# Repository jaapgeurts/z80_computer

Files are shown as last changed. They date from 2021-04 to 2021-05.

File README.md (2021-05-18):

# Sea80 1648 : Z80 Homebrew computer

This project contains the following subprojects

1. Hardware Schematic and PCB design
2. Retro8 compiler - compiler for z80
3. Firmware, rom monitor, gal files, general test utilities

System clock: 7,372,800 Hz

Notes to self:
My z80 and peripheral chips have been relabeled(sanded and repainted) by Chinese sellers. The SIO in my system is a SIO/0

# Hardware

##  Memory map

Memory is divided into 8K block

0000-1FFF = ROM chip U6
2000-3FFF = ROM chip U7
4000-5FFF = RAM chip U8
6000-7FFF = RAM chip U9
8000-9FFF \
A000-BFFF } RAM chip U10
C000-DFFF |
E000-FFFF /

0000-3FFF = (16k) ROM
4000-EFFF = (45k) USER RAM
F000-FFFF = (4k)  SYSTEM RAM

### System ram
F000 - F4AF = Character Screen Ram
F4B0 - FEFF = System variables
FF00 -      = Keyboard buffer
FF80 - FFFF - System stack (128 bytes)

## IO memory map

Memory IO is divided into 8 blocks of 32 bytes each
0x00 - Z84-3000, Timer/Counter
0x20 - RTC27421, Realtime Clock
0x40 - Z84-4000, Serial IO
0x60 - Z84-2000, Parallel IO
0x80 - AY-8910, Sound
0xA0 - ILI9488, LCD Display,
0xC0 - CF, Compact Fash, IDE interface
0xE0 - Free

## Screen - ILI9488

Ports: 0xA0, 0xA1

TFT driver IC is ILI9488 in 8bit parallel interface mode.

The screen is a graphics screen and supports one mode. Characters drawn are blitted from ROM to the screen and is backed by a character array.
Resolution: 480x320
Text output resolution: 60x20 characters

## GPIO

There are four GPIO groups divided over three GPIO headers.
Each group is mapped to a port.

Group A & B are mapped to port A and port B of the Z84C2004
Group C & D are mapped to port A and port B of the AY-3-8910

### PSG

Ports:0x80 (Register select), 0x81 (Data)
Register map: R7(dir), R15 (Input), R15 (Output)

Since port A and port B have on-board devices connected, the direction should be programmed as indicated below:

|GPIO|PSG Port|I/O |
|----|---|---|
|PC2 | A2 | Input only|
|PC3 | A3 | Input only|
|PC4 | A4 | Input only|
|PC5 | A5 | Input only|
|PC6 | A6 | Input only|
|PC7 | A7 | Input only|

|GPIO|PSG Port|I/O |
|----|---|---|
|PD4 | B4 |Output only|
|PD5 | B5 |Output only|
|PD6 | B6 |Output only|
|PD7 | B7 |Output only|

Port D outputs are open collector and buffered throught a ULN2008. Sinking is limited to max 500ma for all pins together. So 500ma is shared between all outputs; i.e. two pins can sink 250ma each etc..

### Z84C2010 PIO

Ports: 0x40

|GPIO |Z84C2004 Port|I/O  |
|---|---|-----|
|PA0 | A0 | I/O |
|PA1 | A1 | I/O |
|PA2 | A2 | I/O |
|PA3 | A3 | I/O |
|PA4 | A4 | I/O |
|PA5 | A5 | I/O |
|PA6 | A6 | I/O |
|PA7 | A7 | I/O |
|PARDY  | ARDY | I/O |
|/PASTB | ASTB | I/O |

|GPIO |Z84C2004 Port|I/O  |
|---|---|-----|
|PB0 | B0 | I/O |
|PB1 | B1 | I/O |
|PB2 | B2 | I/O |
|PB3 | B3 | I/O |
|PB4 | B4 | I/O |
|PB5 | B5 | I/O |
|PB6 | B6 | I/O |
|PB7 | B7 | I/O |
|PBRDY  | BRDY | I/O |
|/PBSTB | BSTB | I/O |

Port A can source 1.6ma, Port B can source 5ma per pin.
Port A & B can both sink max 15ma per pin.

Note: This device does not have a RESET line and must be reset in software.

### Buzzer

The buzzer is connected to PSG port B0

### Leds

The three leds are active HIGH and connected to PSG port B.
Led 1 = Pin B1
Led 2 = Pin B2
Led 3 = Pin B3

### Buttons

All buttons are active LOW.

The two user buttons are connected to the PSG port A.

BTN 1 = Pin A0
BTN 2 = Pin A1

NMI is connected directly to the NMI interrupt of the CPU

RESET is connected directly connected to reset line of board

## Timer - Z84C3010 CTC

Ports: 0x00

System clock = 7,372,800 Hz
Baudrate clock on CLK/TRG0 = 3,686,400 Hz

Period = 1/ClockFreq * Prescaler * TimeConstant

Or rewritten:

Tc = (C * I) / P
where Tc = TimeConstant
      C = Clock in Hz
      I = Interval in s (largest interval is 0.008888...s or 112.5 Hz)
      P = PreScaler = 256 or 16

The minimum and maximum interval range of the timer is: ~2.17us - ~0.009s or 460,800Hz - 112.5Hz

### Timer/Counter header

## RS232 - Z84C4010 SIO/0

Ports: 0x40(UART A data), 0x41(UART B data), 0x42(UART A control), 0x43(UART b control)

Standard TTL level.
Default 9600, 8N1

## PSG - AY-3-8910

Ports: 0x80(Register select) & 0x81 (Data)

Input frequency: 1,843,200 Hz

Register map:

|Register|Description |B7-B0 |
|---|---|---|
|R0 |Channel A Period |8bits fine |
|R1 | |Low nibble coarse|
|R2 |Channel B Period |8bits fine |
|R3 | |Low nibble coarse|
|R4 |Channel C Period |8bits fine |
|R5 | |Low nibble coarse|
|R6 |Noise Period |5 low bits period|
|R7 |/Enable ||
|R8 |Channel A Amplitude ||
|R9 |Channel B Amplitude ||
|R10 |Channel C Amplitude ||
|R11 |Envelope Period |8bits fine |
|R12 |Envelope Period |8bits course |
|R13 |Envelope Shape/Cycle||
|R14 |Port A |8bits data |
|R15 |Port B |8bits data |

## Realtime Clock - RTC72421

Port: 0x20-0x2F

## Compact Flash

Ports: 0xC0

Follows standard IDE interface.

## PS/2 Keyboard

## POST indicators

Explain led errors
01 001
02 010
03 011
04 100
05 101
06 110
07 111

## Soft power

Not working. Design error

## Errata

Bodge wires

# Software

## Available functions
## RST vectors
## Interrupts

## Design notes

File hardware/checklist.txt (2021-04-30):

Checklist before fabrication

DONE 1. Check all unused/free ports are added added to headers
DONE 2. Check all unused inputs are not floating
DONE 3. Check reset button can be bridged by jumper (for external button)
DONE 4. Check critical traces can be cut for installing bodges
DONE 5. check zilog datasheets for direction of pins
DONE 6. double check wiring on pins of all ICs (following datasheets). Check pins too
DONE 7. check clock freq on PSG
DONE 8. PS/2 buffer + PS/2 host->dev communication
DONE 9. Add port buffers where necessary
DONE 10. Check all wiring lightup in kicad
DONE 11. Add 5v input plug; bypassing regulator
DONE 12. Test points?
DONE 13. check each chip has 100n bypass cap
DONE 14. lcd displays: check which side is top. (orientation)
WONTDO 15. add led for halt 
DONE 16. power led
DONE 17. label ports
DONE 18. add expansion port 
WONTDO 19. add jumpers for clock speed
DONE 20. NMI button
DONE 21. 3 user leds (r g b)
DONE 22. 3 user buttons
DONE 23. show switch settings on silkscreen
DONE 24. show battery type on silkscreen
DONE 25. show port pinouts on silkscreen
26. check pcb power switch if it matches footprint
DONE 27. check ic pincounts on pcb
DONE 28. verify orientation of the compact flash card connector and pin assignments/wiring
DONE 29. bring values to silkscreen layer
DONE 30. add revision to PCB / add logo / add name
DONE 31. add via stiching
DONE 32. Add board holes for compactflash screws
33. Check edges make sure that ground runs around all board edges
34. write max current draw/sink for GPIO, default speed for serial
35. label areas and what they do
36. add buzzer
37. label speaker with +/-
38. audio jack out. connect ring ground
39. connect pwr of 2676 to gnd
40. ps/2 connector is reversed
41. change led order connections so that it matches the output bits
42. label GALS io or mem

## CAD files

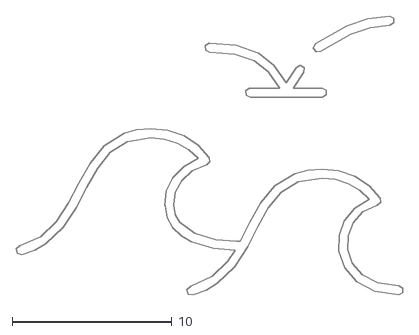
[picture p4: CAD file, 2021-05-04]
assets/wav_logo.dxf
24.2 x 17.5

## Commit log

2021-03-03 Split into modules
    [inputoutput.sch, romram.sch, soundio.sch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]
2021-03-07 Added PIO to schematic
2021-05-04 added assets
    [wav_logo.dxf]
